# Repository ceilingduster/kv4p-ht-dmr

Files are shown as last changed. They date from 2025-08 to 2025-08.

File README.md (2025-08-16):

# VA3IAN-DMR
This modification of the KV4P-HT project is an example of swapping the SA8X8 hardware module with NiceRF's DMR818S-5W module.  This keeps the support for Analog RF on UHF or VHF (350Mhz as well in countries that support it), but adds the capability of DMR.

# Credit
Open source handheld ham radio project based on KV4p-HT by Vance Vagell (KV4P) — licensed under the GNU General Public License v3.
This product includes modifications. The full source code (including the modifications) is available at: 
https://github.com/VanceVagell/kv4p-ht

Please see the main project site: https://kv4p.com.  Thank you Vance for an incredible project!  This MOD is only meant to serve to innovate and support the greater project.

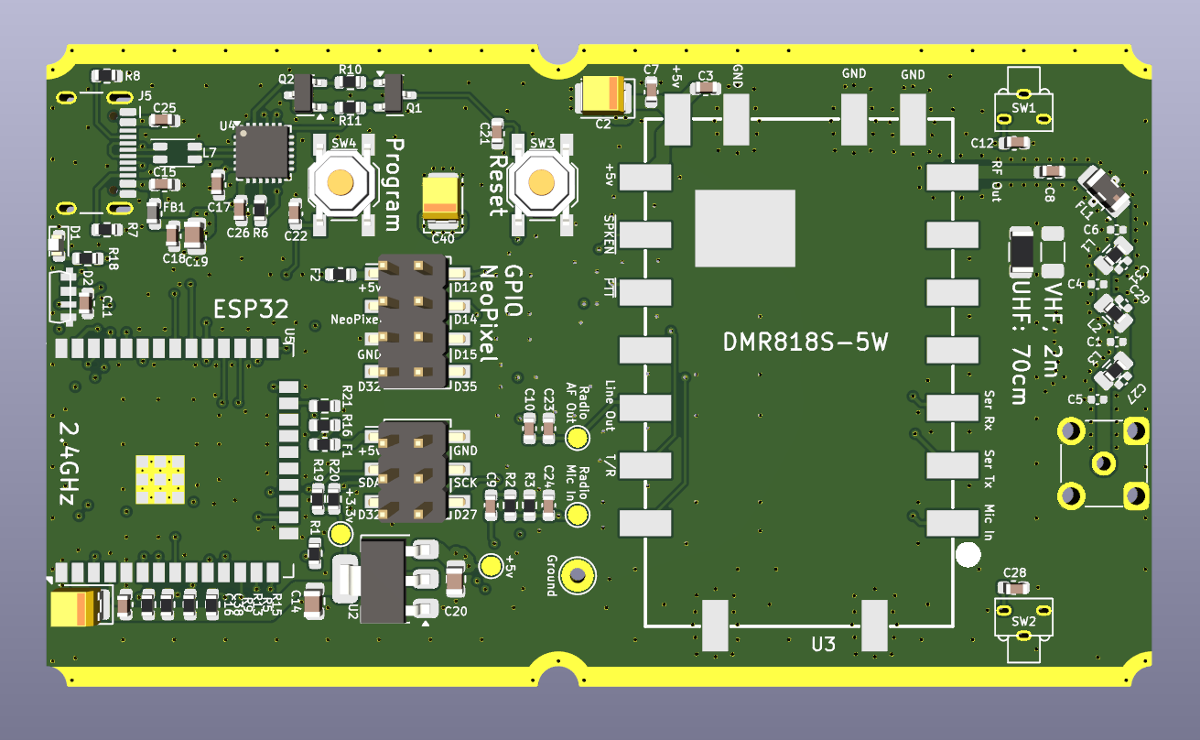
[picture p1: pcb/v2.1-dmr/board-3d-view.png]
PCB Board with DMR818S-5W module


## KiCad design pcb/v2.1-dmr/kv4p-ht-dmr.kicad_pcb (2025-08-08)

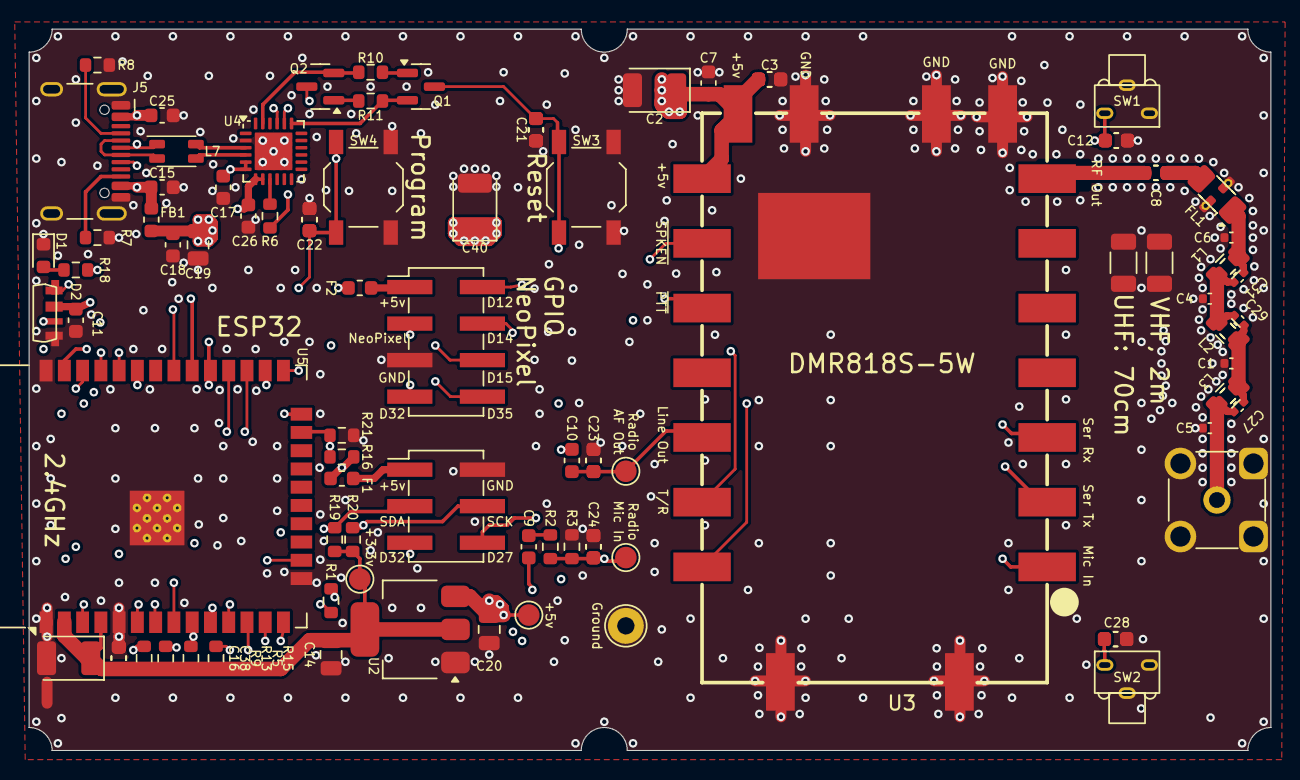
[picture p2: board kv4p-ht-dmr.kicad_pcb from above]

Board: 4 copper layers, 86.4 x 50.2 mm, 95 parts (0 on the bottom side), 54 nets.

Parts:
C1: 18pF; C_0402_1005Metric
C2, C16, C40: 100uF 6.3v; CP_EIA-3528-21_Kemet-B
C3, C8, C12, C21, C22, C23, C24, C28, C38: 2.2nF Tuned VHF; C_0603_1608Metric
C4: 16pF; C_0402_1005Metric
C5: 10pF; C_0402_1005Metric
C6: 5.1pF; C_0402_1005Metric
C7, C11, C18, C26: 100nF; C_0603_1608Metric
C9, C10, C17: 1uF; C_0603_1608Metric
C13, C30, C32, C33, C34, C35, C36, C37, C39: 220pF Tune UHF; C_0603_1608Metric
C14, C19, C20: 10uF; C_0805_2012Metric
C15, C25: 100pF; C_0603_1608Metric
C27: 2.7pF; C_0402_1005Metric
C29: 13pF; C_0402_1005Metric
C31: 11pF; C_0402_1005Metric
D1: Red; LED_0603_1608Metric
D2: SK6812SIDE-4020; LED_SK6805_SIDE
F1, F2: 100mA; Fuse_0603_1608Metric
FB1: Ferrite Bead, 1A; L_0603_1608Metric
FL1: LFCN-490+; Filter_Mini-Circuits_FV1206
J1: Antenna; Conn_SMA_Close-to-board-edge
J2: SAO v.69bis; PinHeader_2x03_P2.54mm_Vertical_SMD
J3: GPIO Header; PinHeader_2x04_P2.54mm_Vertical_SMD
J5: USB-C Socket; USB_C_Receptacle_HCTL_HC-TYPE-C-16P-01A
L1: 27nH; L_0805_2115Metric (Murata Inductors)
L2: 30nH; L_0805_2115Metric (Murata Inductors)
L3: 43nH; L_0805_2115Metric (Murata Inductors)
L4, L5, L6: L_0603_1608Metric
L7: CMCC; L_CommonMode_Wurth_WE-CNSW-1206
Q1, Q2: SS8050; SOT-23
R1, R16, R21: 100k; R_0603_1608Metric
R2, R5, R9, R10, R11, R13, R15: 10k; R_0603_1608Metric
R3, R6, R18, R19, R20: 1.2k; R_0603_1608Metric
R4: 0R; R_1206_3216Metric
R7, R8: 5.1k; R_0603_1608Metric
R12, R14, R17: 0R; R_0603_1608Metric
R22: VHF; R_1206_3216Metric
R23: UHF; R_1206_3216Metric
SW1, SW2: PTT; SW-Push-SPST-Horizontal-C455252
SW3: Reset; SW_SPST_TL3342
SW4: Program; SW_SPST_TL3342
TP1: +5v; TestPoint_Pad_D1.5mm
TP2: +3.3v; TestPoint_Pad_D1.5mm
TP3: Gnd; TestPoint_THTPad_D2.5mm_Drill1.2mm
TP4: Radio Mic; TestPoint_Pad_D1.5mm
TP5: Radio Line Out; TestPoint_Pad_D1.5mm
U2: AZ1117H-3.3TRG1; SOT-223-3_TabPin2
U3: WIRELM-SMD_G-NICERF_DMR818-AMBE-X
U4: CP2102N-A02-GQFN24; QFN-24-1EP_4x4mm_P0.5mm_EP2.6x2.6mm
U5: ESP32-WROOM-32E-N4; ESP32-WROOM-32D

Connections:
+3.3V: C14.2, C16.1, C38.1, C39.2, R5.1, R9.2, R13.2, R15.1, R19.2, R20.2, TP2.1, U2.2 (VO), U5.2 (VDD), U5.4 (SENSOR_VP)
+5V: C2.1, C3.1, C7.1, C11.1, C18.1, C19.2, C20.2, C26.1, C30.2, C40.1, D2.2 (VDD), F1.1, F2.1, FB1.2, R16.1, TP1.1, U2.3 (VI), U3.11 (VCC), U3.12 (VCC), U4.7 (VREGIN), U4.8 (VBUS)
/ADC Bias: R1.1, U5.11 (IO26)
/Enable/~Reset: C21.1, C37.2, Q1.3 (C), R9.1, SW3.1 (A), U5.3 (EN)
/GPIO0/~Program: C22.1, C34.2, Q2.3 (C), R13.1, SW4.1 (A), U5.25 (IO0)
/GPIO12: J3.2, U5.14 (IO12)
/GPIO14: J3.4, U5.13 (IO14)
/GPIO15: J3.6, R16.2, R21.1, U5.23 (IO15)
/GPIO27: J2.6, U5.12 (IO27)
/GPIO32: J2.5, J3.7, U5.8 (IO32)
/GPIO35: J3.8, U5.7 (IO35)
/NeoPixel DI: D2.1 (DIN), U5.16 (IO13)
/NeoPixel DO: D2.3 (DOUT), J3.3
/PTT Button Left: C28.1, C36.2, R5.2, SW2.1, U5.9 (IO33)
/PTT Button Right: C12.1, C35.2, R15.2, SW1.2, U5.29 (IO5)
/Radio ANT: C8.2, C13.2, U3.7 (ANT)
/Radio CS: U3.13 (CS), U5.37 (IO23)
/Radio Line Out: C10.2, C23.1, C33.2, TP5.1, U3.16 (LINE_OUT)
/Radio Mic In: C24.1, C32.2, R2.1, R3.2, TP4.1, U3.1 (MIC_IN)
/Radio Rx: U3.3 (UART-RX), U5.28 (IO17)
/Radio SPKEN: U3.18 (SPKEN), U5.26 (IO4)
/Radio Tx: U3.2 (UART-TX), U5.27 (IO16)
/Radio T/R: U3.17 (T/R), U5.31 (IO19)
/Radio ~PTT: U3.14 (PTT), U5.30 (IO18)
/SAO SCK: J2.4, R20.1, U5.36 (IO22)
/SAO SDA: J2.3, R19.1, U5.33 (IO21)
/Stock LED: R18.1, U5.24 (IO2)
/USB Rx: U4.20 (RXD), U5.35 (TXD0/IO1)
/USB Tx: U4.21 (TXD), U5.34 (RXD0/IO3)
/~DTR: Q2.2 (E), R10.2, U4.23 (~DTR)
/~RTS: Q1.2 (E), R11.2, U4.19 (~RTS)
GND: C1.1, C2.2, C3.2, C4.1, C5.1, C6.1, C7.2, C11.2, C12.2, C14.1, C15.1, C16.2, C17.2, C18.2, C19.1, C20.1, C21.2, C22.2, C23.2, C24.2, C25.1, C26.2, C28.2, C30.1, C32.1, C33.1, C34.1, C35.1, C36.1, C37.1, C38.2, C39.1, C40.2, D1.1 (K), D2.4 (VSS), FL1.2 (GND), FL1.4 (GND), J1.2 (Ext), J2.2, J3.5, J5.A1 (GND), J5.A12 (GND), J5.B1 (GND), J5.B12 (GND), J5.S1 (SHIELD), R3.1, R7.2, R8.2, R21.2, R22.1, R22.2, R23.1, R23.2, SW1.1, SW1.SH (B), SW2.2, SW2.SH (B), SW3.2 (B), SW4.2 (B), TP3.1, U2.1 (GND), U3.8 (GND), U3.9 (GND), U3.10 (GND), U3.19 (GND), U3.20 (GND), U3.21 (EP), U4.2 (GND), U4.25 (GND), U5.1 (GND), U5.5 (SENSOR_VN), U5.15 (GND), U5.38 (GND), U5.39 (GND)
unnamed: C1.2, C27.2, C29.1, L2.1, L3.2, L4.2, L5.1, R12.1, R14.2
unnamed: C9.1, R2.2
unnamed: C4.2, C29.2, C31.1, L1.1, L2.2, L5.2, L6.1, R14.1, R17.2
unnamed: D1.2 (A), R18.2
unnamed: C6.2, C31.2, FL1.1 (IN), L1.2, L6.2, R4.2, R17.1
unnamed: C8.1, C13.1, FL1.3 (OUT), R4.1
unnamed: C5.2, C27.1, J1.1 (In), L3.1, L4.1, R12.2
unnamed: F1.2, J2.1
unnamed: F2.2, J3.1
unnamed: J5.A5 (CC1), R8.1
unnamed: J5.B5 (CC2), R7.1
unnamed: J5.A6 (D+), J5.B6 (D+), L7.1
unnamed: J5.A7 (D-), J5.B7 (D-), L7.4
unnamed: Q1.1 (B), R10.1
unnamed: Q2.1 (B), R11.1
unnamed: L7.2, U4.3 (D+)
unnamed: L7.3, U4.4 (D-)
unnamed: C17.1, R6.2, U4.5 (VIO), U4.6 (VDD)
unnamed: R6.1, U4.9 (~RST)
unnamed: C9.2, U5.10 (IO25)
unnamed: C10.1, R1.2, U5.6 (IO34)
VBUS: C15.2, C25.2, FB1.1, J5.A4 (VBUS), J5.A9 (VBUS), J5.B4 (VBUS), J5.B9 (VBUS)

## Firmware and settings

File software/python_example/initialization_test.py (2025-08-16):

#!/usr/bin/env python3
# -*- coding: utf-8 -*-
"""
===========================================================
 Script Name:   initialization_test.py
 Author:        Ian Redden
 Created:       2025-08-15
 Description:   Initializes DMR858S modules from NiceRF
 Version:       1.0
===========================================================

Usage:
    python initialization_test.py

Notes:
    - In config section below, set the variables
    - Requires Python 3.13+, pySerial

Changelog:
    v1.0 - Initial release.
"""

__author__    = "Ian Redden"
__email__     = "iredden@gmail.com"
__version__   = "1.0"
__license__   = "MIT"
__status__    = "Development"  # Other values: "Production", "Prototype"

import time
import struct
import threading
import queue
from dataclasses import dataclass
from typing import Optional, Tuple, Callable, Dict
import serial  # pyserial


# ---------- Packet model ----------
@dataclass
class Packet:
    head: int = 0x68
    cmd: int = 0x01          # Example command
    rw_flag: int = 0x01      # 0x00=read, 0x01=write
    sr_flag: int = 0x01      # 0x01=start, 0x00=done (module->host uses other values)
    checksum: int = 0x0000   # (not used by module; included for completeness)
    length: int = 0
    data: bytes = b""
    tail: int = 0x10

    def to_bytes(self) -> bytes:
        self.length = len(self.data)
        return (
            struct.pack("!BBBBHH",
                        self.head, self.cmd, self.rw_flag, self.sr_flag,
                        self.checksum, self.length)
            + self.data
            + struct.pack("!B", self.tail)
        )

    @classmethod
    def from_bytes(cls, packet: bytes):
        try:
            head, cmd, rw_flag, sr_flag, checksum = struct.unpack("!BBBBH", packet[:6])
            data_length = struct.unpack("!H", packet[6:8])[0]
            data = packet[8:8 + data_length]
            tail = packet[8 + data_length]
        except Exception:
            return None
        if head != 0x68 or tail != 0x10:
            return None
        return cls(head, cmd, rw_flag, sr_flag, checksum, data_length, data, tail)


# ---------- Config ----------
PORT = "COM1"              #
BAUD = 57600               # No need to change baud rate.  It likes 57,600!

RX_HZ = 444_462_500        # 444.462500 MHz
TX_HZ = 449_462_500        # 449.462500 MHz
RADIO_ID = 1_234_456       # 3-byte big-endian
TG = 1                     # talkgroup
TG_TYPE = 2                # 1 = private, 2 = group, 4 = all
TS = 1                     # timeslot (1 or 2)
COLOR_CODE = 1             # color code (0-15)

# ---------- Command builders ----------
def frame(cmd: int, payload: bytes = b"") -> bytes:
    print(payload.hex(" "))
    return Packet(cmd=cmd, rw_flag=0x01, sr_flag=0x01, data=payload).to_bytes()

def cmd_reset():                      # 0xF0: payload 1A 01
    return frame(0xF0, b"\x1A\x01")

def cmd_check_init():                 # 0x1A, payload 01
    return frame(0x1A, b"\x01")

def cmd_set_contact_id(contact_id: int, contact_type: int):
    return frame(0x18, contact_type.to_bytes(1, "big") + contact_id.to_bytes(3, "big"))

def cmd_set_freq(tx_hz: int, rx_hz: int):   # 0x0D, TX then RX, little-endian
    return frame(0x0D,
                 tx_hz.to_bytes(4, "little")
                 + rx_hz.to_bytes(4, "little"))

def cmd_set_timeslot(timeslot: int): # either 0x01 or 0x02
    return frame(0x33, timeslot.to_bytes(1, "big"))

def cmd_set_color_code(color_code: int):
    return frame(0x31, color_code.to_bytes(1, "big"))

def cmd_set_radio_id(radio_id: int):
    return frame(0x1B, radio_id.to_bytes(3, "big"))

def cmd_disable_encryption():
    return frame(0x19, b"\xff")

def cmd_check_current_channel():
    return frame(0x1D, b"\x01")

def cmd_clear_rx_group():
    return frame(0x30, b"\x01")

def cmd_add_contact_to_rx_group(rx_group_id: int, contact_id: int):
    return frame(0x29, rx_group_id.to_bytes(1, "big") + contact_id.to_bytes(3, "big"))

# ---------- Serial link with send queue & reader ----------
class SerialLink:
    """
    - send(bytes): enqueue a frame to write
    - request(bytes, expect_cmd, timeout): send and block waiting for a reply whose cmd == expect_cmd
    - add_rx_hook(cmd, fn): register a passive callback for frames matching cmd (non-blocking observers)
    """
    def __init__(self, port: str, baud: int, inter_frame_gap: float = 0.010):
        self.port_name = port
        self.baud = baud
        self.inter_frame_gap = inter_frame_gap

        self.ser: Optional[serial.Serial] = None
        self._send_q: "queue.Queue[bytes]" = queue.Queue()
        self._rx_q: "queue.Queue[bytes]" = queue.Queue()

        # waiters keyed by expected cmd -> list of queues to signal
        self._waiters: Dict[int, "queue.Queue[bytes]"] = {}

        # optional passive hooks per cmd
        self._hooks: Dict[int, Callable[[bytes], None]] = {}

        self._stop = threading.Event()
        self._writer_t = threading.Thread(target=self._writer_loop, daemon=True)
        self._reader_t = threading.Thread(target=self._reader_loop, daemon=True)
        self._dispatcher_t = threading.Thread(target=self._dispatch_loop, daemon=True)

    def open(self):
        self.ser = serial.Serial(self.port_name, self.baud, timeout=0.05)
        print(f"[port] opened {self.port_name} @ {self.baud}")
        self._stop.clear()
        self._writer_t.start()
        self._reader_t.start()
        self._dispatcher_t.start()

    def close(self):
        self._stop.set()
        # Put sentinels to unblock queues
        try:
            self._send_q.put_nowait(b"")
            self._rx_q.put_nowait(b"")
        except Exception:
            pass
        # Close serial after threads have a chance to exit
        time.sleep(0.1)
        if self.ser and self.ser.is_open:
            self.ser.close()
            print("[port] closed")

    # ---- public API ----
    def send(self, frame_bytes: bytes):
        """Fire-and-forget send (queued; non-blocking)."""
        self._send_q.put(frame_bytes)

    def request(self, frame_bytes: bytes, expect_cmd: int, timeout: float = 1.0) -> Optional[bytes]:
        """
        Send, then wait for first received frame with cmd==expect_cmd (across all traffic).
        Returns raw frame bytes or None on timeout.
        """
        waiter_q: "queue.Queue[bytes]" = queue.Queue(maxsize=1)
        self._register_waiter(expect_cmd, waiter_q)
        try:
            print(f">> {frame_bytes.hex(" ")}")
            self._send_q.put(frame_bytes)
            try:
                return waiter_q.get(timeout=timeout)
            except queue.Empty:
                return None
        finally:
            self._unregister_waiter(expect_cmd, waiter_q)

    def add_rx_hook(self, cmd: int, fn: Callable[[bytes], None]):
        """Passive observer for frames of a given cmd (does not consume waiter slots)."""
        self._hooks[cmd] = fn

    # ---- internal: writer/read/dispatch ----
    def _writer_loop(self):
        while not self._stop.is_set():
            try:
                item = self._send_q.get(timeout=0.05)
            except queue.Empty:
                continue
            if not item:
                continue
            if self.ser and self.ser.is_open:
                try:
                    self.ser.write(item)
                except Exception as e:
                    print(f"[writer] write error: {e}")
            time.sleep(self.inter_frame_gap)  # gentle pacing

    def _parse_call(self, hex_bytes: bytes):
        if len(hex_bytes) != 4:
            raise ValueError("Expected exactly 4 bytes")

        call_type = hex_bytes[0]  # first byte
        radio_id = int.from_bytes(hex_bytes[1:], byteorder="big")  # last 3 bytes, MSB first

        call_types = {
            1: "Private Call",
            2: "Group Call",
            4: "All Call"
        }

        return {
            "call_type": call_types.get(call_type, f"Unknown ({call_type})"),
            "radio_id": radio_id
        }
        
    def _debug_frame(self, frame_bytes: bytes):
        print(f"<< {frame_bytes.hex(" ")}")

        if frame_bytes.startswith(b"\x68"):
            # Decode the packet
            pkt = Packet.from_bytes(frame_bytes)
            if pkt:
                # Print packet details
                print(f"[debug] cmd=0x{pkt.cmd:02X} rw=0x{pkt.rw_flag:02X} sr=0x{pkt.sr_flag:02X} "
                    f"len={pkt.length} data={pkt.data.hex(' ')}")

                if pkt.cmd == 0x06 and pkt.sr_flag == 0x60:
                    # convert pkt.data.hex msb to integer
                    print(self._parse_call(pkt.data))
            else:
                print("[debug] invalid frame format")

    def _reader_loop(self):
        buf = bytearray()
        while not self._stop.is_set():
            try:
                if not self.ser or not self.ser.is_open:
                    time.sleep(0.05)
                    continue
                chunk = self.ser.read(self.ser.in_waiting or 1)
                if not chunk:
                    continue
                buf.extend(chunk)

                # Extract frames
                while True:
                    # find header
                    try:
                        i = buf.index(0x68)
                    except ValueError:
                        buf.clear()
                        break
                    if i:
                        del buf[:i]
                    if len(buf) < 8:
                        break
                    ln = (buf[6] << 8) | buf[7]
                    need = 8 + ln + 1
                    if len(buf) < need:
                        break
                    frame_bytes = bytes(buf[:need])
                    del buf[:need]
                    if frame_bytes.endswith(b"\x10"):
                        self._debug_frame(frame_bytes)                        
                        self._rx_q.put(frame_bytes)
                    else:
                        # bad tail; slide 1
                        pass
            except Exception as e:
                print(f"[reader] error: {e}")
                time.sleep(0.05)

    def _dispatch_loop(self):
        while not self._stop.is_set():
            try:
                fr = self._rx_q.get(timeout=0.05)
            except queue.Empty:
                continue
            if not fr:
                continue

            pkt = Packet.from_bytes(fr)
            if not pkt:
                continue

            # Notify any waiter expecting this cmd
            waiters = self._waiters.get(pkt.cmd)
            if waiters:
                # deliver to first waiter (typical request/response)
                try:
                    wq = waiters.pop(0)
                    wq.put_nowait(fr)
                except Exception:
                    pass

            # Call passive hook if any
            hook = self._hooks.get(pkt.cmd)
            if hook:
                try:
                    hook(fr)
                except Exception as e:
                    print(f"[hook {pkt.cmd:02X}] error: {e}")

    def _register_waiter(self, cmd: int, qobj: "queue.Queue[bytes]"):
        self._waiters.setdefault(cmd, []).append(qobj)

    def _unregister_waiter(self, cmd: int, qobj: "queue.Queue[bytes]"):
        lst = self._waiters.get(cmd)
        if not lst:
            return
        try:
            lst.remove(qobj)
        except ValueError:
            pass
        if not lst:
            self._waiters.pop(cmd, None)


# ---------- Helpers built on SerialLink ----------
def wait_for_port(port: str, baud: int, retry_delay=0.3) -> SerialLink:
    while True:
        try:
            link = SerialLink(port, baud)
            link.open()
            return link
        except Exception:
            time.sleep(retry_delay)

def wait_init_done(link: SerialLink, total_timeout=10.0, ping_every=0.25) -> bool:
    """
    Poll 0x1A until we see module reply with cmd==0x1A and sr_flag==0x00 (Done).
    """
    t0 = time.time()
    last = 0.0

    # Passive hook prints unexpected SR codes for 0x1A
    def hook(fr: bytes):
        pkt = Packet.from_bytes(fr)
        if pkt and pkt.sr_flag not in (0x00,):  # non-done states
            print(f"[init] status cmd=0x1A sr=0x{pkt.sr_flag:02X}")

    link.add_rx_hook(0x1A, hook)

    while time.time() - t0 < total_timeout:
        now = time.time()
        if now - last >= ping_every:
            link.send(cmd_check_init())
            last = now

        # Non-blocking check: wait up to ping_every for a 0x1A
        fr = link.request(cmd_check_init(), expect_cmd=0x1A, timeout=ping_every)
        if fr:
            pkt = Packet.from_bytes(fr)
            if pkt and pkt.rw_flag == 0x00:  # module->host 'read'
                if pkt.sr_flag == 0x00:
                    print("[init] module reports Done")
                    return True
                elif pkt.sr_flag == 0x09:
                    print("[init] checksum error (unexpected)")
                    # keep looping
    return False

# ---------- Main ----------
def main():
    # Optional hard reset then re-open (uncomment if you wire reset)
    link = wait_for_port(PORT, BAUD)
    link.send(cmd_reset())
    link.close()

    time.sleep(3)

    # wait for port
    link = wait_for_port(PORT, BAUD)
    
    # the order below of initialization cmds matters!
    try:
        # Poll 0x1A until Done
        if not wait_init_done(link, total_timeout=12.0):
            print("[init] timeout waiting for 0x1A Done; exiting")
            return

        # Set Transmit Frequency
        resp = link.request(cmd_set_freq(TX_HZ, RX_HZ), expect_cmd=0x0D, timeout=1)
        if resp: print(f"[set_freq] ack received {resp.hex(" ")}")

        # Set Timeslot
        resp = link.request(cmd_set_timeslot(TS), expect_cmd=0x33, timeout=1)
        if resp: print(f"[set_timeslot] ack received {resp.hex(" ")}")

        # Set Color Code
        resp = link.request(cmd_set_color_code(COLOR_CODE), expect_cmd=0x31, timeout=1)
        if resp: print(f"[set_color_code] ack received {resp.hex(" ")}")

        # Set Radio ID
        resp = link.request(cmd_set_radio_id(RADIO_ID), expect_cmd=0x1B, timeout=1)
        if resp: print(f"[set_radio_id] ack received {resp.hex(" ")}")

        # Set Disable Encryption
        resp = link.request(cmd_disable_encryption(), expect_cmd=0x19, timeout=1)
        if resp: print(f"[disable_encryption] ack received {resp.hex(" ")}")
        
        # clear receive group list
        resp = link.request(cmd_clear_rx_group(), expect_cmd=0x30, timeout=1)
        if resp: print(f"[clear_rx_group] ack received {resp.hex(" ")}")
        
        # add contact to receive group list (use receive group 32)
        resp = link.request(cmd_add_contact_to_rx_group(32, TG), expect_cmd=0x29, timeout=1)
        if resp: print(f"[add_contact_to_rx_group] ack received {resp.hex(" ")}")

        # Set Contact ID
        resp = link.request(cmd_set_contact_id(TG, TG_TYPE), expect_cmd=0x19, timeout=1)
        if resp: print(f"[set_contact_id] ack received {resp.hex(" ")}")

        print("[DONE] DMR module Programmed.")

        # Keep reading in background; foreground just idle
        while True:
            time.sleep(0.5)

    except KeyboardInterrupt:
        pass
    finally:
        link.close()


if __name__ == "__main__":
    main()

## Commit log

2025-08-08 Swapped SA8X8 for DMR818S-5W
    [kv4p-ht-dmr.kicad_pcb, kv4p-ht-dmr.kicad_sch]
2025-08-16 Update README.md and added PCB Board
